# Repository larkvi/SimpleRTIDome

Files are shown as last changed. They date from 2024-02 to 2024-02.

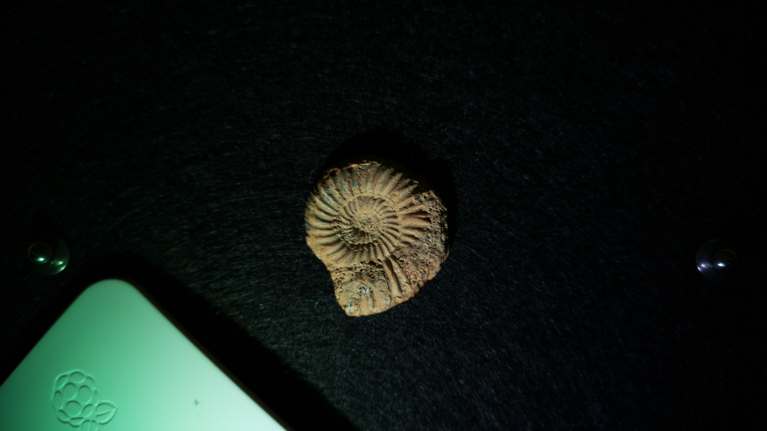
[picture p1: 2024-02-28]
examples/v2/batch_013_fossil/013_25_rti.jpg

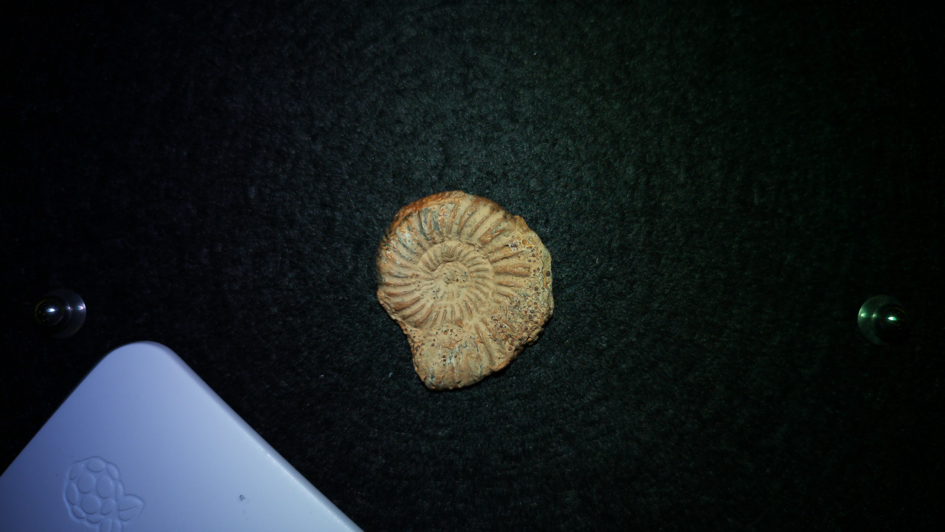
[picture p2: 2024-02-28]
examples/v2/batch_013_fossil/013_39_rti.jpg

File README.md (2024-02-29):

# SimpleRTIDome

A GitHub supporting and documenting a simple—and inexpensive—DIY camera-agnostic (/camera-integrated) Refectance Transformation Imaging (RTI) dome, suitable for teaching and experimentation. The goal of this project is to use simple, off-the-shelf components with no special "maker" skills required (other than acquiring the 3D prints, which is unavoidable). The system consists of a Raspberry Pi Zero (WH/2WH) with appropriate cables (USB for headless operation; a power cable, keyboard, hdmi cable, and mouse for desktop operation), a Raspberry Pi Camera Module 3 (or USB-connected external camera with macro lens), a string of addressable LEDs, and three female-to-male breadboard cables. The provided scripts automate the workflow of creating a directory, turning on each light in turn, taking an image, and naming it appropriately for construction of an RTI file using the [ReLight](https://vcg.isti.cnr.it/relight/) software. With the integrated Raspberry Pi Camera Module 3 configuration, it can photograph items of no more than 7cm x 7cm (HxW) and can focus up to 1cm from the base, which effectively creates a depth limit of approximately 1.5cm. It is my hope that this simple to assemble and inexpensive dome will allow wider classroom use and the availability of the tool for loan to students learning about the technology. This project also forms the basis for a larger, research-quality dome, but that has not been fully prototyped yet, and will require at least basic soldering and wiring skills (but no custom board/controllers, as in other home-made RTI dome plans).

3D printing files have been uploaded for the v2 version of the prototype. These files work, but are due to be rebuilt shortly to amend small issues. Due to delays in receiving parts from China, the v3 version (hopefully the release version) is not expected until June 2024 at the earliest. If you have interest or feedback, please feel free to use the issues feature or get in contact via email.

There are three scripts currently included in the repository. Due to a fundamental issue with the Neopixels library, they currently must be run with `sudo`, which is less than desirable for many reasons, not the least because the files written will be owned by root. Until a workaround is developed, it is necessary to use the `chgrp -R` and `chown -R` commands on the parent folder of the resulting files after each use, in order to facilitate copying and use by non-root processes.

`prelight.py` is mainly used for variants of the dome that do not have the integrated Raspberry Pi Camera Module 3 in them, where a DSLR is being used instead. It allows the lighting of a few pixels for the purpose of focus and exposure. Note that due to the power draw, only a few LEDs should be lit at oncewhile the power is being provided by the Raspberry Pi board (if using an external power source, be sure to make the correct circuit between the board and the string of lights to avoid providing too much power to the board).

`rti_loop_gphoto2.py` is used when connecting the dome to a USB camera, such as a DSLR.

`rti_loop_picam2.py` is called when using the integrated Raspberry Pi Camera Module 3.

The difference between the two commands is the library that is used in order to communicate with the camera. It is intended to merge them in the future, and allow the passing of all commands as arguments on the command line. At the moment, the simplest way to use either, in my opinion, is to open the Thonny editor using `sudo thonny` and edit the variables at the top to name batches and the like.

More information and build plans will be posted shortly.

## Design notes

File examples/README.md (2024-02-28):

# SimpleRTIDome Examples

These will eventually be moved into a different respository, but for now, here are exampl outputs of the prototype domes. V2 is the current version, with some color balance issues to be worked out. In order to view the RTI files, download the [ReLight application](https://vcg.isti.cnr.it/relight/) and when selcting the view option, choose the `output` folder in each example folder (the others are the raw files).

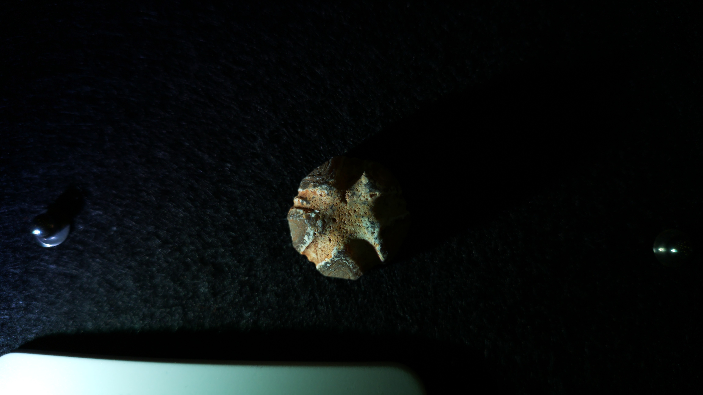
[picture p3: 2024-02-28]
examples/v2/batch_012_oddrock/012_02_rti.jpg

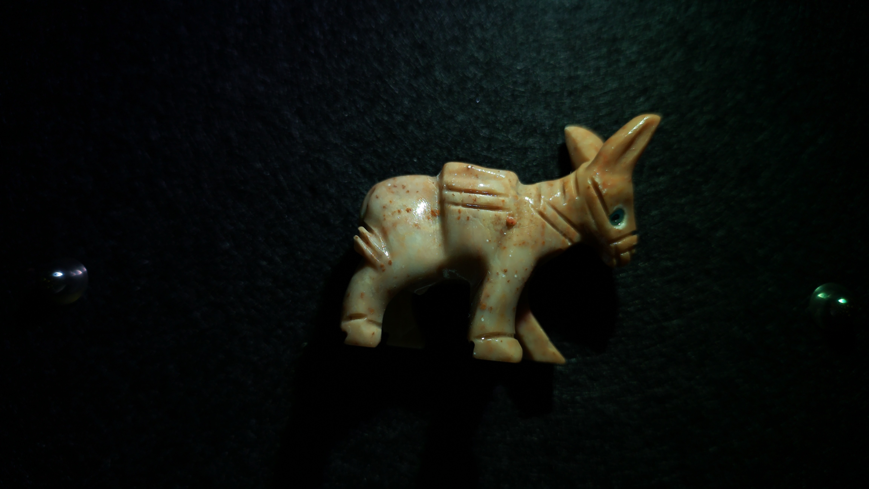
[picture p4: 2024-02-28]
examples/v2/batch_011_donkey/011_19_rti.jpg

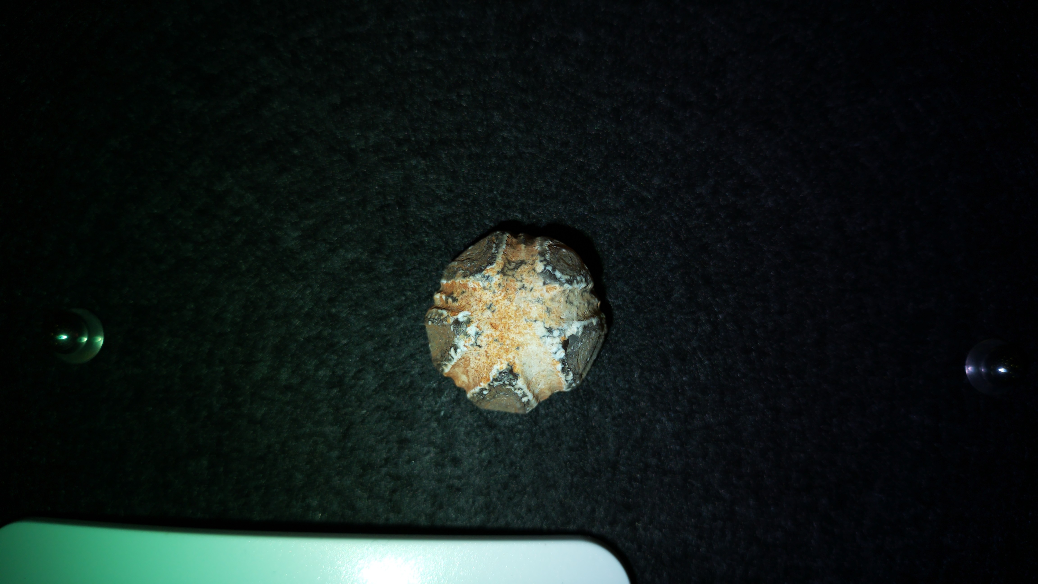
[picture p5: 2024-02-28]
examples/v2/batch_012_oddrock/012_36_rti.jpg

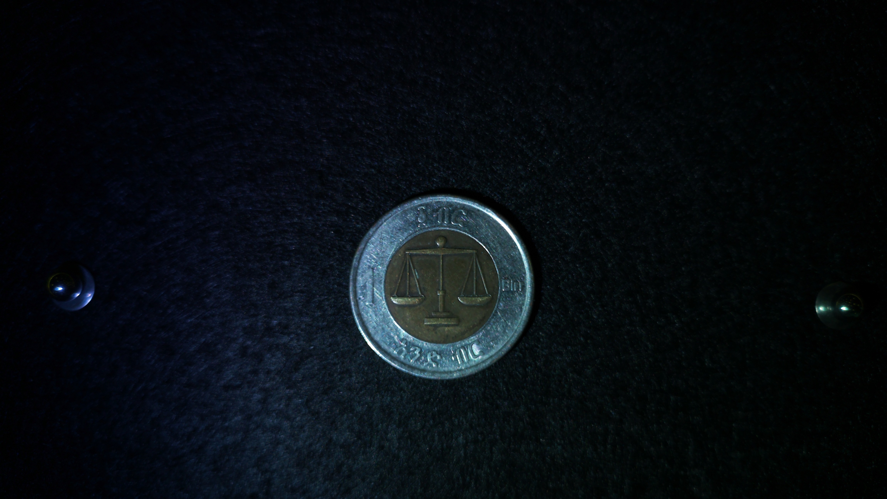
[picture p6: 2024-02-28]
examples/v2/batch_010_onebirrcoin/010_35_rti.jpg

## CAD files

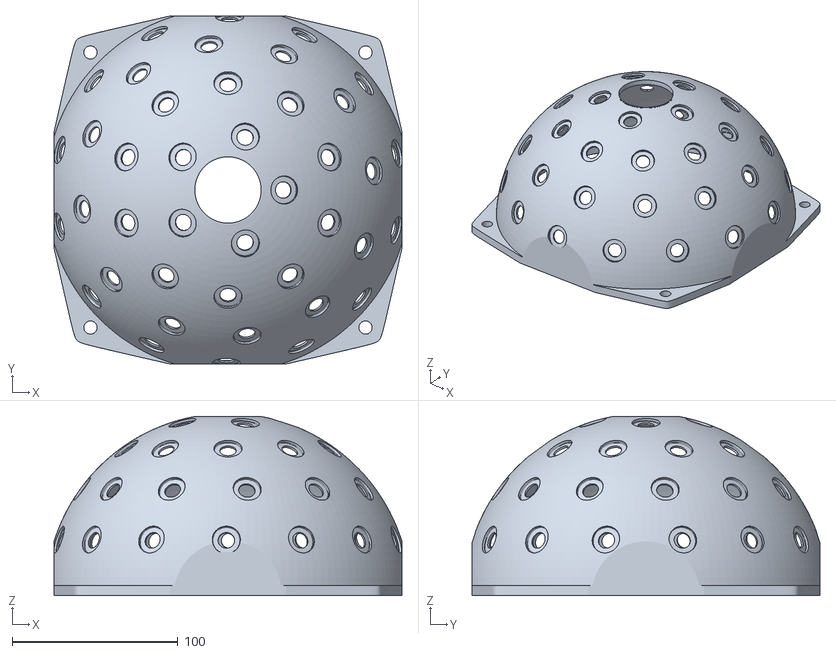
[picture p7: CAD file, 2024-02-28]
3d_print_files/v2_prototype/SimpleRTIDome_11cm_noplate_210mmfootprint_v6.stl
210.0 x 210.0 x 108.2

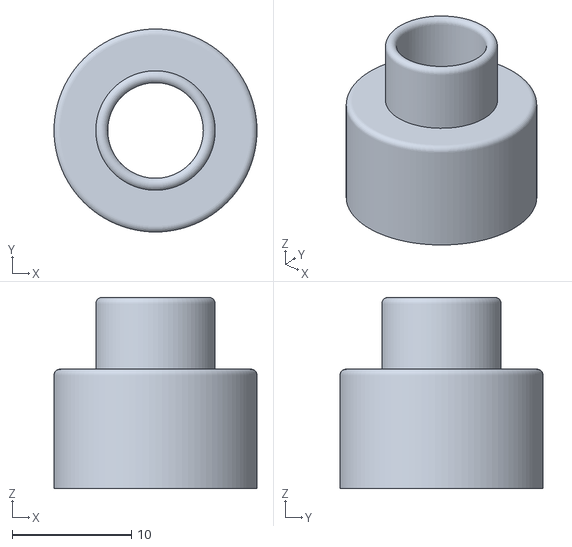
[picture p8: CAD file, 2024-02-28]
3d_print_files/v2_prototype/LED Sleeve v4.stl
17.0 x 17.0 x 16.0

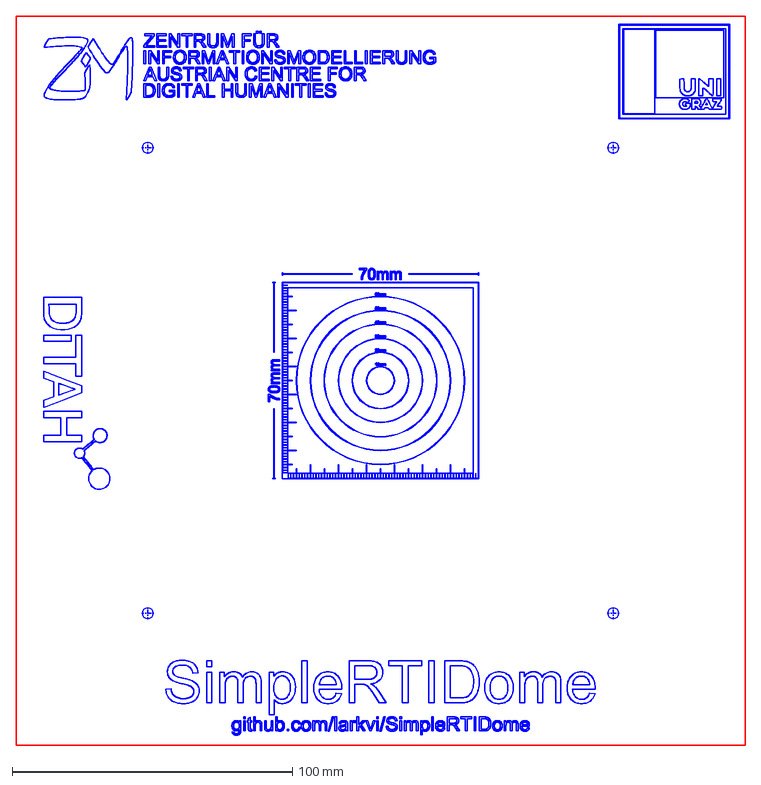
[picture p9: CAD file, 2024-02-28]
3d_print_files/v2_prototype/SimpleRTI_LaserCutter_BasePlate.dxf
260.0 x 260.0 mm

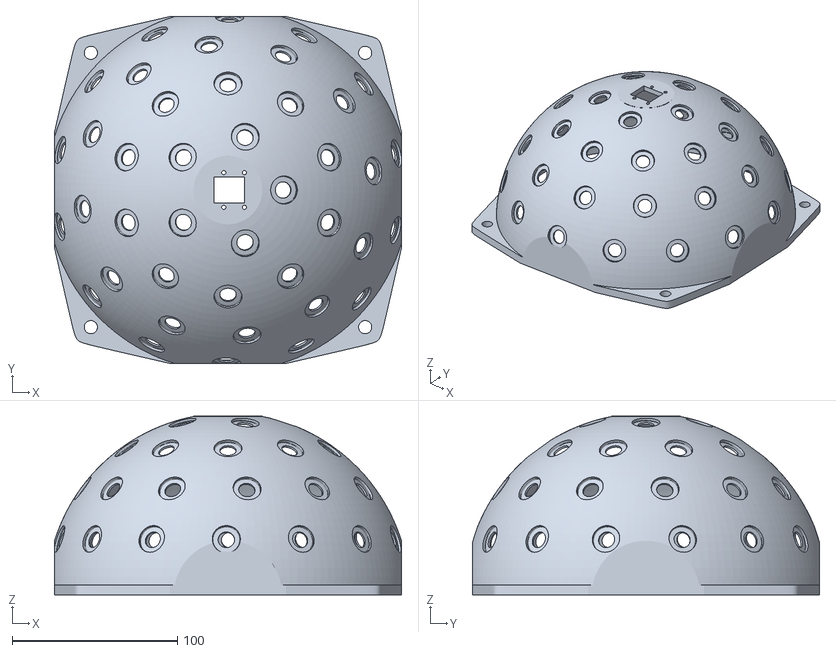
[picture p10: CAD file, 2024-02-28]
3d_print_files/v2_prototype/SimpleRTIDome_11cm_bare_210mmfootprint v6.stl
210.0 x 210.0 x 108.2

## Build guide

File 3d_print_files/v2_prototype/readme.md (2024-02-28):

# SimpleRTIDome v2 print files

There are four files in this directory:
- 	SimpleRTIDome_11cm_bare_210mmfootprint v6.stl is the current 3D printing file for the dome with integrated Raspberry Pi Camera Module 3 mounnting plate
-   SimpleRTIDome_11cm_noplate_210mmfootprint_v6.stl is the current 3D printing file with no mounting plate for the RasPi camera, just a hole. It is more suitable for use with a DSLR with a macro lens.
-   LED Sleeve v4.stl is the file for printing the LED sleeves. Though 41 are needed, it is probably better to print extras in case you ruin one during the cleaning (we didn't, but just in case). Due to its small size, it is probably advantageous to print plates of them separately from the main dome.
-   SimpleRTI_LaserCutter_BasePlate.dxf is an untested (at your own risk! let me know if it works!) laser file for laser cutting a base with markings for the alignment holes and a measuring plate for the field of view of the Raspberry Pi Camera Module 3 in its installed state.

The prints were sized for a 210mm footprint, but this unfortunately means that in their current configuration, the travel lines of the printer head will be outside the printable area of a 210mm printer. This will hopefully be rectified in the next model. I used black PETG for the v2 test print, to good effect.

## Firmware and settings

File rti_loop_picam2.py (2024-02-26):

import time
import board
import neopixel
from picamera2 import Picamera2
from libcamera import controls
import os
import subprocess
import sys
import argparse



#import the args here: height of object in mm; exposure compensation if needed; anything else?
#temp: set the user-config values here
base_path = '/home/CameraZero/Pictures/RTI'
batchNumber = 18  #make this increment automatically based upon the current highest-numbered batch -- perhaps the user passes a name (presumably of the object), and then each subsequent call with that name increments?
object_height = 1.95 #height of photographed object in mm

#values below here configure the camera
pixels1 = neopixel.NeoPixel(board.D18, 41, brightness=1) #there are only four acceptable pins for the data. I am using 18.

picam2 = Picamera2()
picam2.configure("capture")
picam2.controls.ExposureTime = 100000
picam2.controls.AnalogueGain = 1.0
picam2.controls.AfMode = controls.AfModeEnum.Manual
picam2.controls.LensPosition = 1000/(110-object_height)
picam2.controls.AwbMode = controls.AwbModeEnum.Daylight

#begin the actual code
def clearPixels():
    pixels1.fill((0,0,0)) #is there a better way to turn the neopixels off?
    return
    
def makeBatchFolder(base_path,batchNumber):
    target_folder = os.path.join(base_path,'batch_'+str(batchNumber).zfill(3))
    print("Target folder: " + target_folder)
    try:
        os.makedirs(target_folder) #makedirs is the plural(recursive) of mkdir for some reason.
    except OSError as error:
        print(error)
    return 
        
def take_the_photo(target_folder,batchNumber,lightNumber):
    target = os.path.join(base_path,'batch_'+str(batchNumber).zfill(3),str(batchNumber).zfill(3)+'_'+str(lightNumber).zfill(2)+'_'+"rti.jpg")
    picam2.capture_file(target)
    print('Writing image to', target)
    return

def lightAndShoot(target_folder,batchNumber,lightNumber):
    picam2.start()
    clearPixels()
    pixels1[lightNumber] = (255,255,255)
    take_the_photo(target_folder,batchNumber,lightNumber)
    clearPixels()
    picam2.stop()
    return

def batchLightAndShoot(base_path,batchNumber): #figure out how to ensure the camera is awake // can gphoto2 wake the camera?
    target_folder = makeBatchFolder(base_path,batchNumber)
    for lightNumber in range (0,41):
        print('Batch: '+str(batchNumber)+'. Image: '+str(lightNumber)+' .')
        lightAndShoot(target_folder,batchNumber,lightNumber)

batchLightAndShoot(base_path,batchNumber)

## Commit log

2023-06-16 sample image and first-pass script
2023-07-06 adding files related to calibration with black marble
2023-07-06 newer calibration images with ruler and known image width of 6.7cm
2023-07-06 reorganize the calibration marble images and outputs
2024-02-26 renamed and split rti_loop into gphoto2 (USB cameras) and Picam2 (RPi Camera Modules) versions. Intend to merge them back into one script later, but for now, this makes it easier to make sure that ea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
2024-02-26 changed .controls to correct .set_controls
    [rti_loop_picam2.py]
2024-02-26 added missing controls from libcamera
    [rti_loop_picam2.py]
2024-02-26 changed set_controls variables to work with correct syntax
    [rti_loop_picam2.py]
2024-02-26 changed and configured controls to target 1.95mm. First pass color balance
2024-02-28 added v2 print and laser files, updated readme, DH2024 poster.
    [LED Sleeve v4.stl, SimpleRTIDome_11cm_bare_210mmfootprint v6.stl, SimpleRTI_LaserCutter_BasePlate.dxf]
2024-02-28 Added no-mounting-plate 3d print dome and readme explaining the files.
    [SimpleRTIDome_11cm_noplate_210mmfootprint_v6.stl]
2024-02-29 warning not to light too many pixels for power reasons
